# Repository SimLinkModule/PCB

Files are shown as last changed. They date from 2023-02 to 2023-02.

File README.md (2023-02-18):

# PCB

There are 3 PCBs in this repo. The ConnectorBoard is responsible for the connection between the radio and the module. The MainBoard contains the ESP32 and a JST GH port for flashing. Flashing works in the same way as the ESP32 devkits with esptool.py. An additional USB-FTDI device is required for this. The IO board contains all the buttons and the display for the user. The PCB was divided into three parts to ensure that it can be installed in a shell as modularly as possible. Also, in the event of circuit faults, you don't have to order everything.

## Notes

- It's important to ensure that a display with 14 pins is used. There are also some displays which are sold with 15 pins.
- If the module always starts in download mode, the capacitor C6 on the main PCB must be removed. C6 is originally responsible for debouncing the button, but puts the ESP32 into flash mode the first time it's booted.

## Used as reference

- schematic of the ESP32 DevKitC development board
- ShenZhen QDTech Co.,LTD 0.91 OLED Schematic und Allvision technology Inc. OEL Display Module Product Specification.

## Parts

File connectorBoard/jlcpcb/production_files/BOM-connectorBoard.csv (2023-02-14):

Comment | Designator | Footprint | LCSC
BAT760-7 | D1 | D_SOD-323F | C124187
LESD8D12T5G | D3 | SOD882 | C172408
LESD8D3.3CAT5G | D2 | SOD882 | C172409
Conn_01x03_Male | J2 | JST_GH_SM03B-GHS-TB_1x03-1MP_P1.25mm_Horizontal | C514175

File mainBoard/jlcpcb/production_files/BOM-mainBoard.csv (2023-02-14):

Comment | Designator | Footprint | LCSC
4.7K | R1,R5,R6 | R_0402_1005Metric | C105871
BAT760-7 | D2 | D_SOD-323F | C124187
10K | R2,R3,R4 | R_0402_1005Metric | C140214
SS8050-G | Q1,Q2 | SOT-23-3 | C164885
0.1u | C3,C5,C6,C7 | C_0402_1005Metric | C2180807
Conn_01x06_Male | J2,J3 | JST_GH_BM06B-GHS-TBT_1x06-1MP_P1.25mm_Vertical | C495534
Conn_01x03_Male | J4 | JST_GH_SM03B-GHS-TB_1x03-1MP_P1.25mm_Horizontal | C514175
AMS1117-3.3 | U1 | SOT-223-3_TabPin2 | C6186
ESP32-WROOM-E | U2 | ESP32-WROOM-32E | C701343
22u | C1,C2,C4 | C_0805_2012Metric | C76634
RED LED | D1 | LED_0603_1608Metric | C84263
Conn_01x01 | J1 | SolderWire-0.25sqmm_1x01_D0.65mm_OD2mm
MountingHole | H2 | MountingHole_2.2mm_M2
MountingHole | H1 | MountingHole_2.2mm_M2
MountingHole | H4 | MountingHole_2.2mm_M2
C520860 | SW1 | SW_SPST_CK_RS282G05A3
C520860 | SW2 | SW_SPST_CK_RS282G05A3
MountingHole | H3 | MountingHole_2.2mm_M2

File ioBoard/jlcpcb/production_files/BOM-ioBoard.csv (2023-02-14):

Comment | Designator | Footprint | LCSC
4.7K | R1,R2,R3,R5,R6 | R_0402_1005Metric | C105871
560K | R4 | R_0402_1005Metric | C131605
Conn_01x06_Male | J1 | JST_GH_SM06B-GHS-TB_1x06-1MP_P1.25mm_Horizontal | C133065
0.1u | C6,C7,C8 | C_0402_1005Metric_Pad0.74x0.62mm_HandSolder | C141382
10u | C3 | C_0402_1005Metric_Pad0.74x0.62mm_HandSolder | C15525
C202424 | SW1,SW2 | SW_SPST_SKQG_WithStem | C202424
1u | C1,C2 | C_0805_2012Metric_Pad1.18x1.45mm_HandSolder | C215803
SS14 | D1 | D_SMA | C2480
4.7u | C5 | C_0402_1005Metric_Pad0.74x0.62mm_HandSolder | C412302
2.2u | C4 | C_0402_1005Metric_Pad0.74x0.62mm_HandSolder | C501836

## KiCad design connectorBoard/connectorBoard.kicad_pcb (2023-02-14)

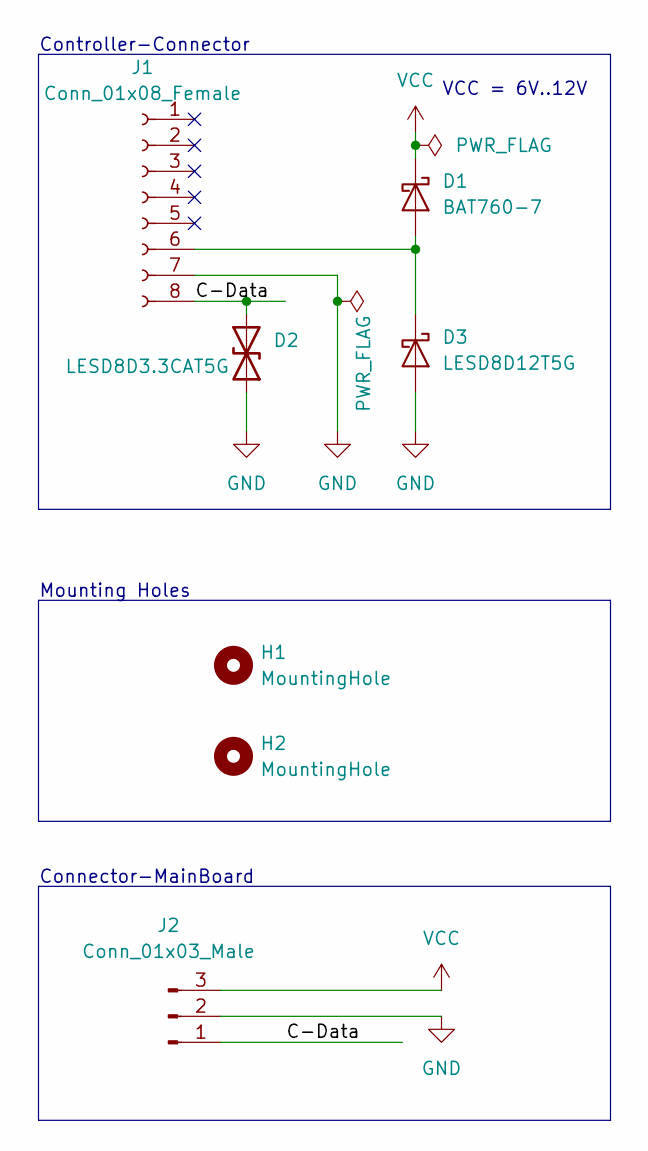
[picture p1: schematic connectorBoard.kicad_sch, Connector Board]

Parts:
D1: BAT760-7; D_SOD-323F
D2: LESD8D3.3CAT5G; SOD882
D3: LESD8D12T5G; SOD882
H1, H2: MountingHole; MountingHole_2.2mm_M2
J1: Conn_01x08_Female; PinSocket_1x08_P2.54mm_Vertical
J2: Conn_01x03_Male; JST_GH_SM03B-GHS-TB_1x03-1MP_P1.25mm_Horizontal

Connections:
/C-Data: D2.2 (A2), J1.8, J2.1
GND: D2.1 (A1), D3.2 (A), J1.7, J2.2
unnamed: D1.2 (A), D3.1 (K), J1.6
VCC: D1.1 (K), J2.3

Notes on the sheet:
Connector-MainBoard
VCC = 6V..12V
Mounting Holes
Controller-Connector

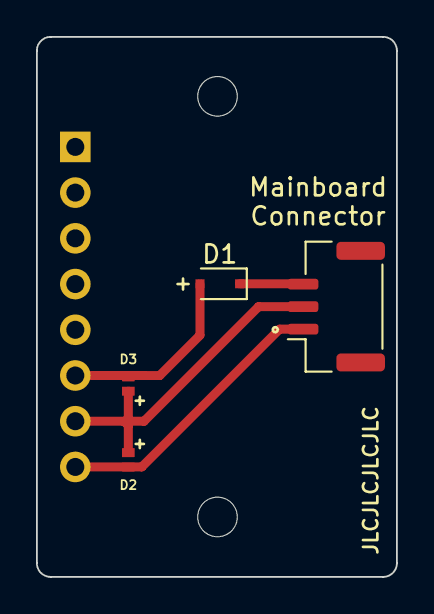
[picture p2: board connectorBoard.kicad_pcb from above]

Board: 2 copper layers, 20.0 x 30.0 mm, 7 parts (1 on the bottom side), 4 nets.

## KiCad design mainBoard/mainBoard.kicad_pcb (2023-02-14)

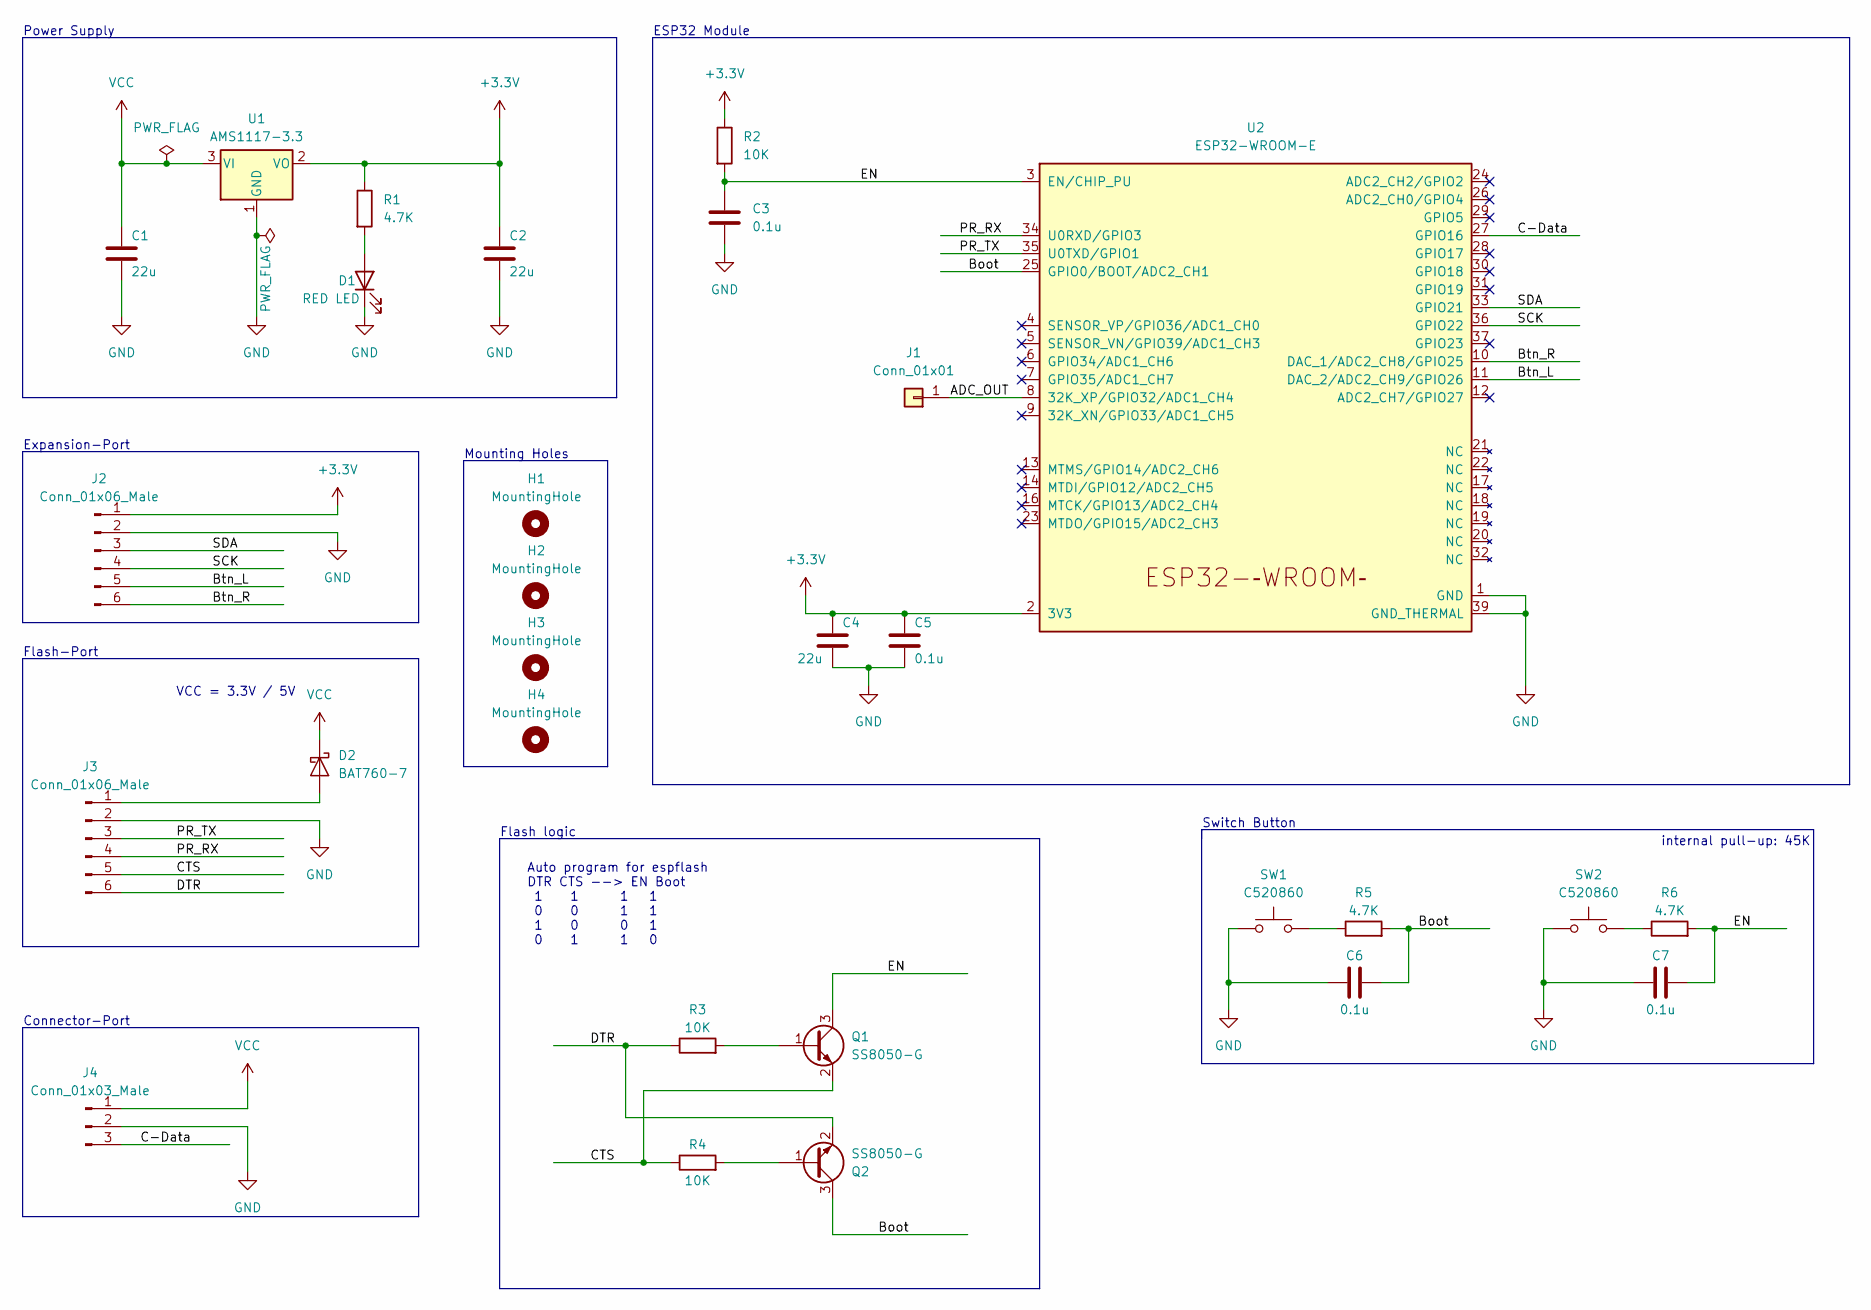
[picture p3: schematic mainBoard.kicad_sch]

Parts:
C1, C2, C4: 22u; C_0805_2012Metric
C3, C5: 0.1u; C_0402_1005Metric
C6, C7: 0.1u; C_0402_1005Metric_Pad0.74x0.62mm_HandSolder
D1: RED LED; LED_0603_1608Metric
D2: BAT760-7; D_SOD-323F
H1, H2, H3, H4: MountingHole; MountingHole_2.2mm_M2
J1: Conn_01x01; SolderWire-0.25sqmm_1x01_D0.65mm_OD2mm
J2, J3: Conn_01x06_Male; JST_GH_BM06B-GHS-TBT_1x06-1MP_P1.25mm_Vertical
J4: Conn_01x03_Male; JST_GH_SM03B-GHS-TB_1x03-1MP_P1.25mm_Horizontal
Q1, Q2: SS8050-G; SOT-23-3
R1, R5, R6: 4.7K; R_0402_1005Metric
R2, R3, R4: 10K; R_0402_1005Metric
SW1, SW2: C520860; SW_SPST_CK_RS282G05A3
U1: AMS1117-3.3; SOT-223-3_TabPin2
U2: ESP32-WROOM-E; ESP32-WROOM-32E

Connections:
+3.3V: C2.1, C4.1, C5.1, J2.1, R1.1, R2.1, U1.2 (VO), U2.2 (3V3)
/ADC_OUT: J1.1, U2.8 (32K_XP/GPIO32/ADC1_CH4)
/Boot: C6.2, Q2.3 (C), R5.2, U2.25 (GPIO0/BOOT/ADC2_CH1)
/Btn_L: J2.5, U2.11 (DAC_2/ADC2_CH9/GPIO26)
/Btn_R: J2.6, U2.10 (DAC_1/ADC2_CH8/GPIO25)
/C-Data: J4.3, U2.27 (GPIO16)
/CTS: J3.5, Q1.2 (E), R4.1
/DTR: J3.6, Q2.2 (E), R3.1
/EN: C3.1, C7.2, Q1.3 (C), R2.2, R6.2, U2.3 (EN/CHIP_PU)
/PR_RX: J3.4, U2.34 (U0RXD/GPIO3)
/PR_TX: J3.3, U2.35 (U0TXD/GPIO1)
/SCK: J2.4, U2.36 (GPIO22)
/SDA: J2.3, U2.33 (GPIO21)
GND: C1.2, C2.2, C3.2, C4.2, C5.2, C6.1, C7.1, D1.1 (K), J2.2, J3.2, J4.2, SW1.1, SW2.1, U1.1 (GND), U2.1 (GND), U2.15 (GND), U2.38 (GND), U2.39 (GND_THERMAL)
unnamed: D1.2 (A), R1.2
unnamed: D2.2 (A), J3.1
unnamed: Q1.1 (B), R3.2
unnamed: Q2.1 (B), R4.2
unnamed: R5.1, SW1.2
unnamed: R6.1, SW2.2
VCC: C1.1, D2.1 (K), J4.1, U1.3 (VI)

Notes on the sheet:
internal pull-up: 45K
ESP32 Module
Switch Button
Connector-Port
Power Supply
Expansion-Port
VCC = 3.3V / 5V
Flash logic
Auto program for espflash DTR CTS --> EN Boot 1 1 1 1 0 0 1 1 1 0 0 1 0 1 1 0
Flash-Port
Mounting Holes

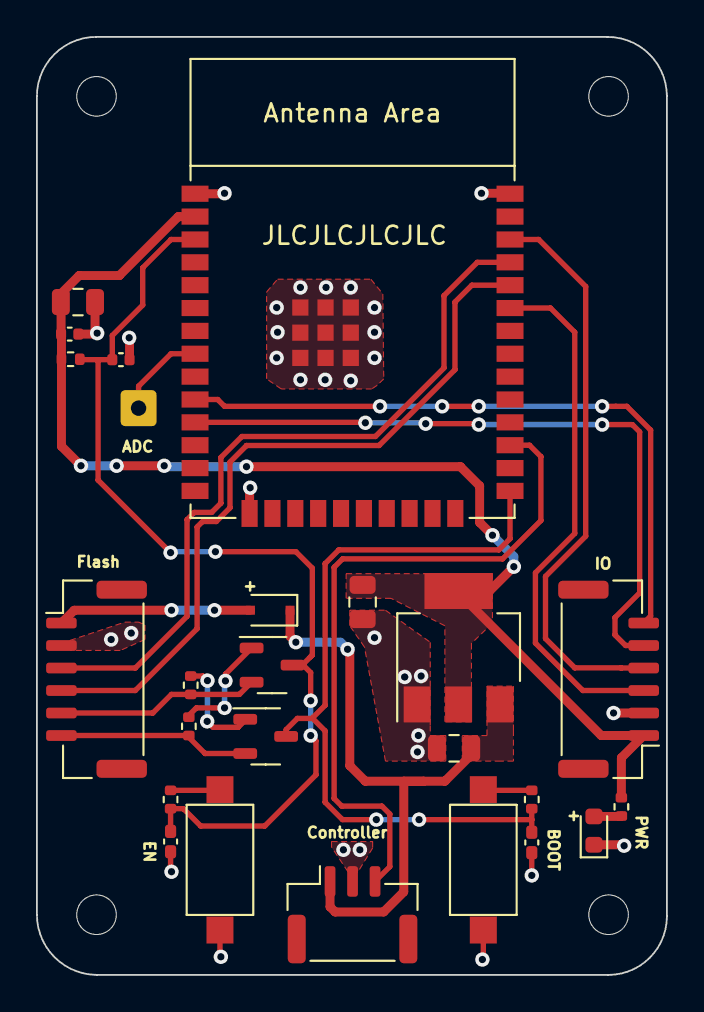
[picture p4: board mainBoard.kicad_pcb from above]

Board: 2 copper layers, 35.0 x 52.1 mm, 29 parts (0 on the bottom side), 21 nets.

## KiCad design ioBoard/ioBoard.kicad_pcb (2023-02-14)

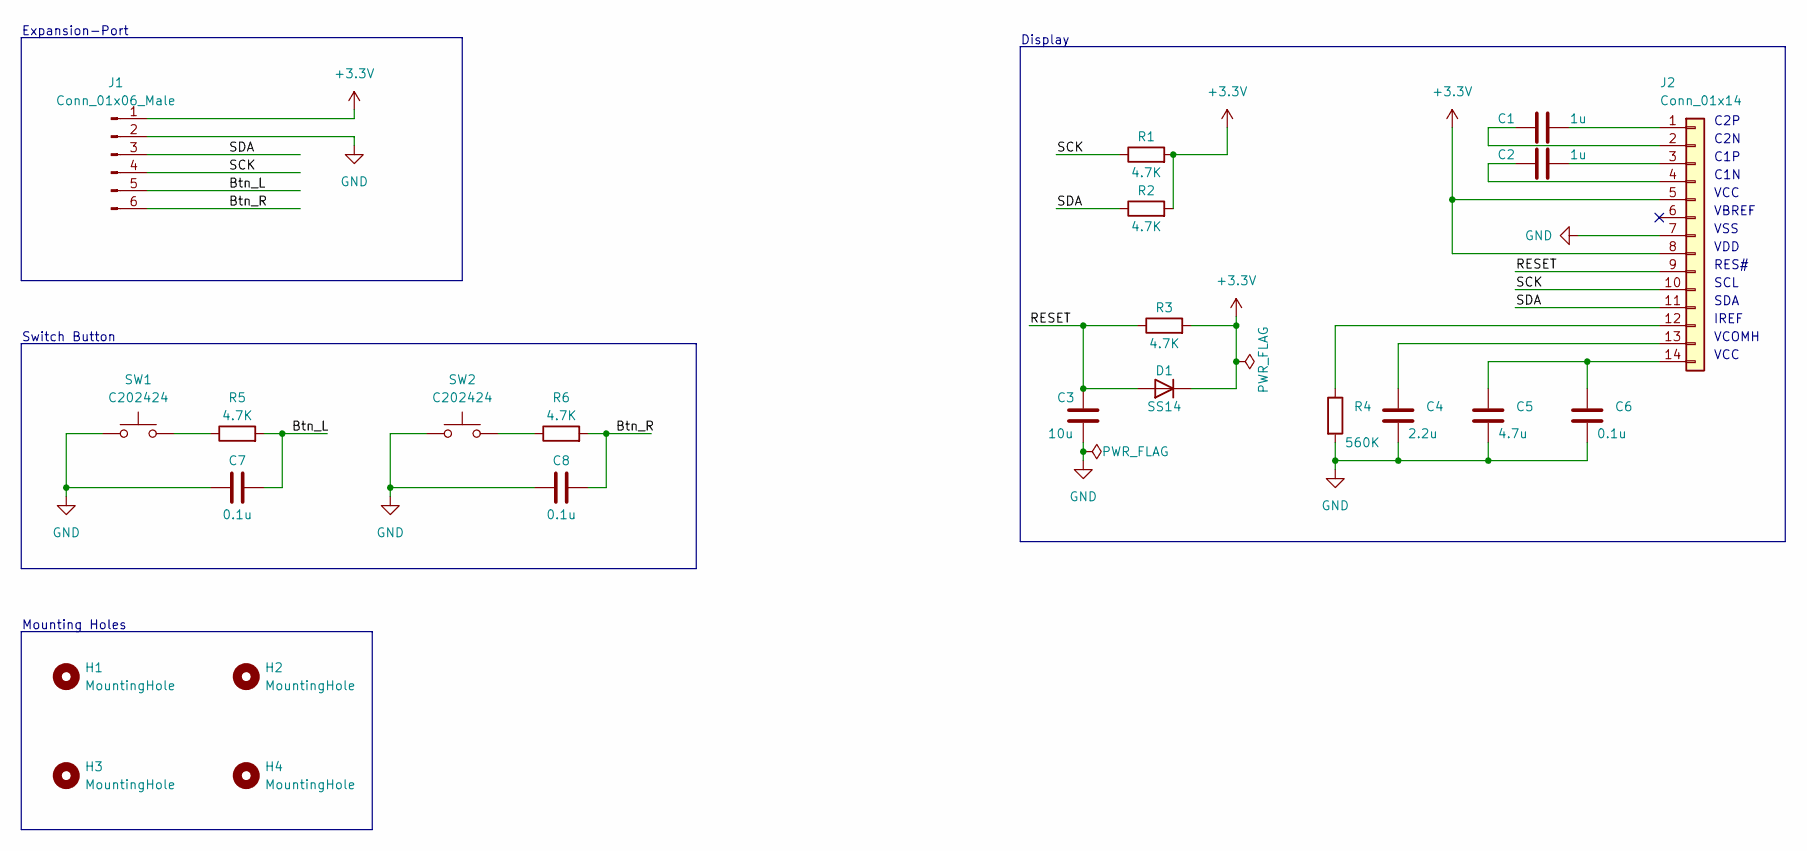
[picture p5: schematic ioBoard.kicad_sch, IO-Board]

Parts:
C1, C2: 1u; C_0805_2012Metric_Pad1.18x1.45mm_HandSolder
C3: 10u; C_0402_1005Metric_Pad0.74x0.62mm_HandSolder
C4: 2.2u; C_0402_1005Metric_Pad0.74x0.62mm_HandSolder
C5: 4.7u; C_0402_1005Metric_Pad0.74x0.62mm_HandSolder
C6, C7, C8: 0.1u; C_0402_1005Metric_Pad0.74x0.62mm_HandSolder
D1: SS14; D_SMA
H1, H2, H3, H4: MountingHole; MountingHole_2.2mm_M2
J1: Conn_01x06_Male; JST_GH_SM06B-GHS-TB_1x06-1MP_P1.25mm_Horizontal
J2: Conn_01x14; SSD1306_Display_14PIN
R1, R2, R3, R5, R6: 4.7K; R_0402_1005Metric
R4: 560K; R_0402_1005Metric
SW1, SW2: C202424; SW_SPST_SKQG_WithStem

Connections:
+3.3V: D1.1 (K), J1.1, J2.5, J2.8, R1.2, R2.2, R3.2
/Btn_L: C7.2, J1.5, R5.2
/Btn_R: C8.2, J1.6, R6.2
/RESET: C3.1, D1.2 (A), J2.9, R3.1
/SCK: J1.4, J2.10, R1.1
/SDA: J1.3, J2.11, R2.1
GND: C3.2, C4.2, C5.2, C6.2, C7.1, C8.1, J1.2, J2.7, R4.2, SW1.1, SW2.1
unnamed: C1.1, J2.1
unnamed: C1.2, J2.2
unnamed: C2.1, J2.3
unnamed: C2.2, J2.4
unnamed: C4.1, J2.13
unnamed: C5.1, C6.1, J2.14
unnamed: J2.12, R4.1
unnamed: R5.1, SW1.2
unnamed: R6.1, SW2.2

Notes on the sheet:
C1N
VSS
SDA
Expansion-Port
Mounting Holes
VCOMH
C1P
Display
IREF
Switch Button
C2P
VDD
SCL
VCC
VBREF
RES#
C2N

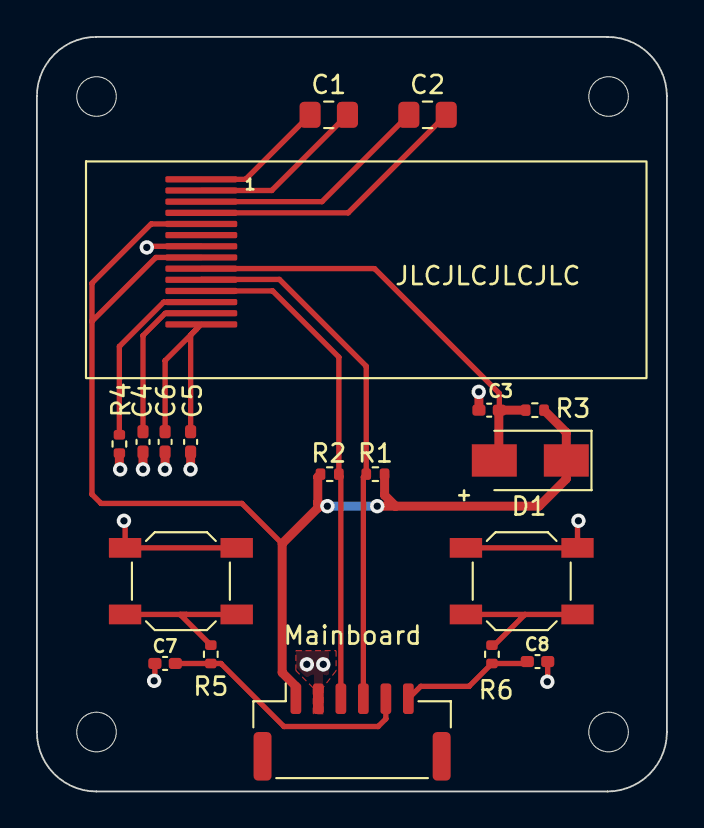
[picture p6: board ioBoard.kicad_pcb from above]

Board: 2 copper layers, 35.0 x 41.9 mm, 23 parts (0 on the bottom side), 16 nets.

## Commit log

2023-01-30 init commit
    [simlinkModule.kicad_pcb, simlinkModule.kicad_sch]
2023-01-30 main pcb basic setup
    [ioboard.kicad_sch, simlinkModule.kicad_sch]
2023-01-31 io board added
    [ioboard.kicad_sch, simlinkModule.kicad_sch]
2023-02-01 esc check done
    [ioboard.kicad_sch, simlinkModule.kicad_sch]
2023-02-02 project restructured
    [ioBoard.kicad_pcb, ioBoard.kicad_sch, ioboard.kicad_sch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]
2023-02-02 added footprints to symbols
    [mainBoard.kicad_pcb, mainBoard.kicad_sch]
2023-02-04 new connector board
    [connectorBoard.kicad_pcb, connectorBoard.kicad_sch, mainBoard.kicad_pcb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]
2023-02-04 added missing connector
    [connectorBoard.kicad_pcb]
2023-02-04 basic connector pcb design
    [connectorBoard.kicad_pcb, connectorBoard.kicad_sch]
2023-02-05 updates for the connector board
    [connectorBoard.kicad_pcb]
2023-02-05 main pcb rough alignment
    [mainBoard.kicad_pcb, mainBoard.kicad_sch]
2023-02-05 routing mainboard done
    [mainBoard.kicad_pcb]
2023-02-05 main pcb for order
    [mainBoard.kicad_pcb]
2023-02-06 io board pcb created
    [ioBoard.kicad_pcb, ioBoard.kicad_sch, mainBoard.kicad_sch]
2023-02-07 jlcpcb orders created
    [connectorBoard-CuBottom.gbr, connectorBoard-CuTop.gbr, connectorBoard-EdgeCuts.gbr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]
2023-02-09 connector and emitter switched
    maybe a problem maybe not
    [mainBoard-CuBottom.gbr, mainBoard-CuTop.gbr, mainBoard-EdgeCuts.gbr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]
2023-02-14 schematic added
